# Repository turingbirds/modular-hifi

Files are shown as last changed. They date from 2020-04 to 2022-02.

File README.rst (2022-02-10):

Modular HiFi
============

A collection of Eurorack modules for home HiFi.

Typically, the PCB serves as a front panel while also carrying the circuit components on the back.

*Status: working prototypes. More documentation will follow!*

Modules
-------

Stereo mixer
~~~~~~~~~~~~

``stereo_3ch_mixer``

Three vertical slider potentiometers. Secondary (monitor) output. Quasi-differential inputs.

Phonograph preamplifier
~~~~~~~~~~~~~~~~~~~~~~~

``phono_preamp``

RIAA preamplifier and subsonic high-pass filter. 

Based on Rod Elliot <http://sound-au.com/> "Project 06" (RIAA pre-amp) and "Project 99" (subsonic filter)

Surround decoder
~~~~~~~~~~~~~~~~

``surround_decoder``

Stereo to 5.1 decoder. Separate volume controls for front, center, rear and subwoofer. Switchable subwoofer low-pass filter, adjustable between 50 and 500 Hz. Rear center channel "mix-in" control.

License
-------

`Open source hardware <https://www.oshwa.org/>`_ is hardware for which the design is made publicly available, so that anyone can study, modify, distribute, make, and sell the design or hardware based on that design, subject to the following license conditions.

Hardware licensed under the *CERN Open Hardware Licence Version 2 - Weakly Reciprocal,* a copy of which is included in this repository at `cern_ohl_w_v2.txt <https://github.com/turingbirds/modular-hifi/blob/master/cern_ohl_w_v2.txt>`_.

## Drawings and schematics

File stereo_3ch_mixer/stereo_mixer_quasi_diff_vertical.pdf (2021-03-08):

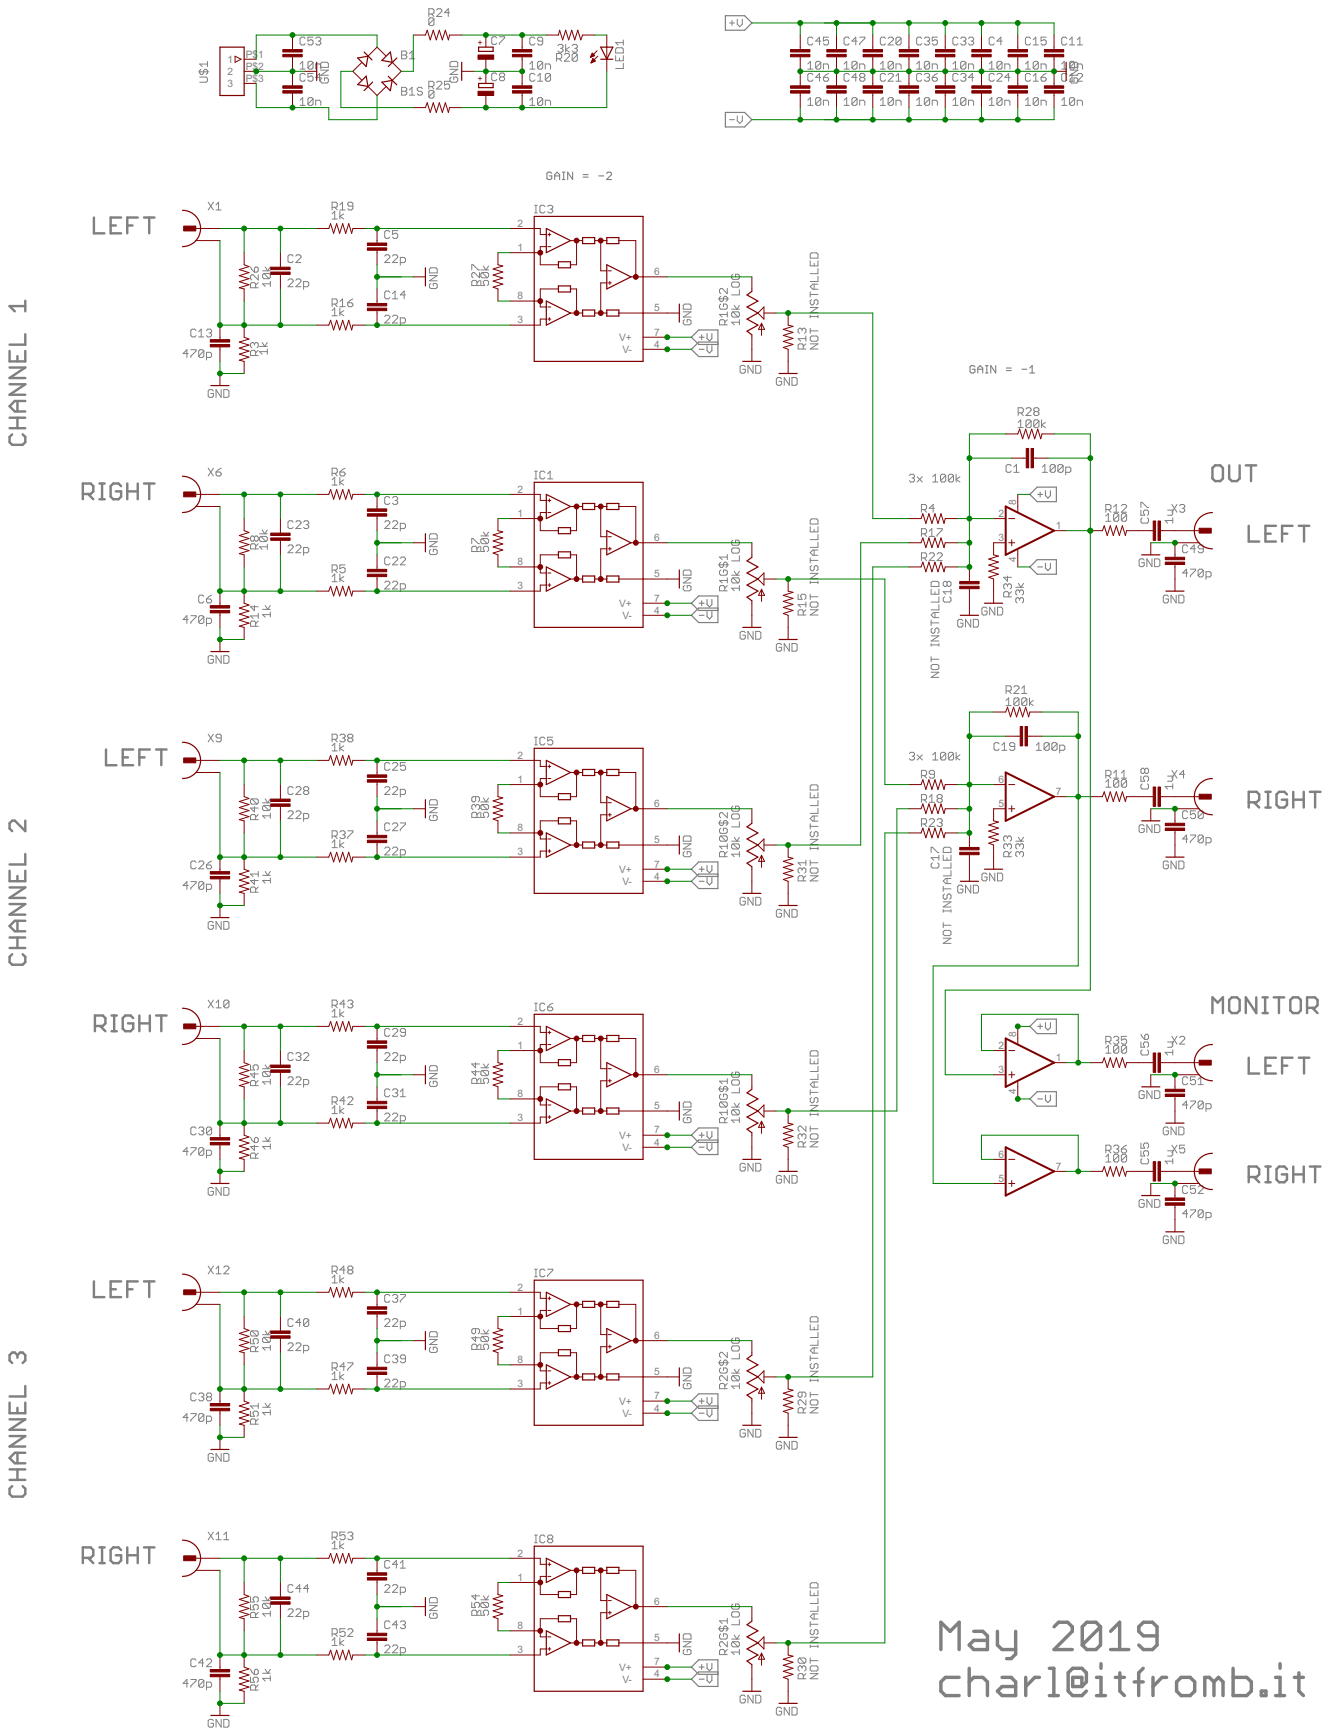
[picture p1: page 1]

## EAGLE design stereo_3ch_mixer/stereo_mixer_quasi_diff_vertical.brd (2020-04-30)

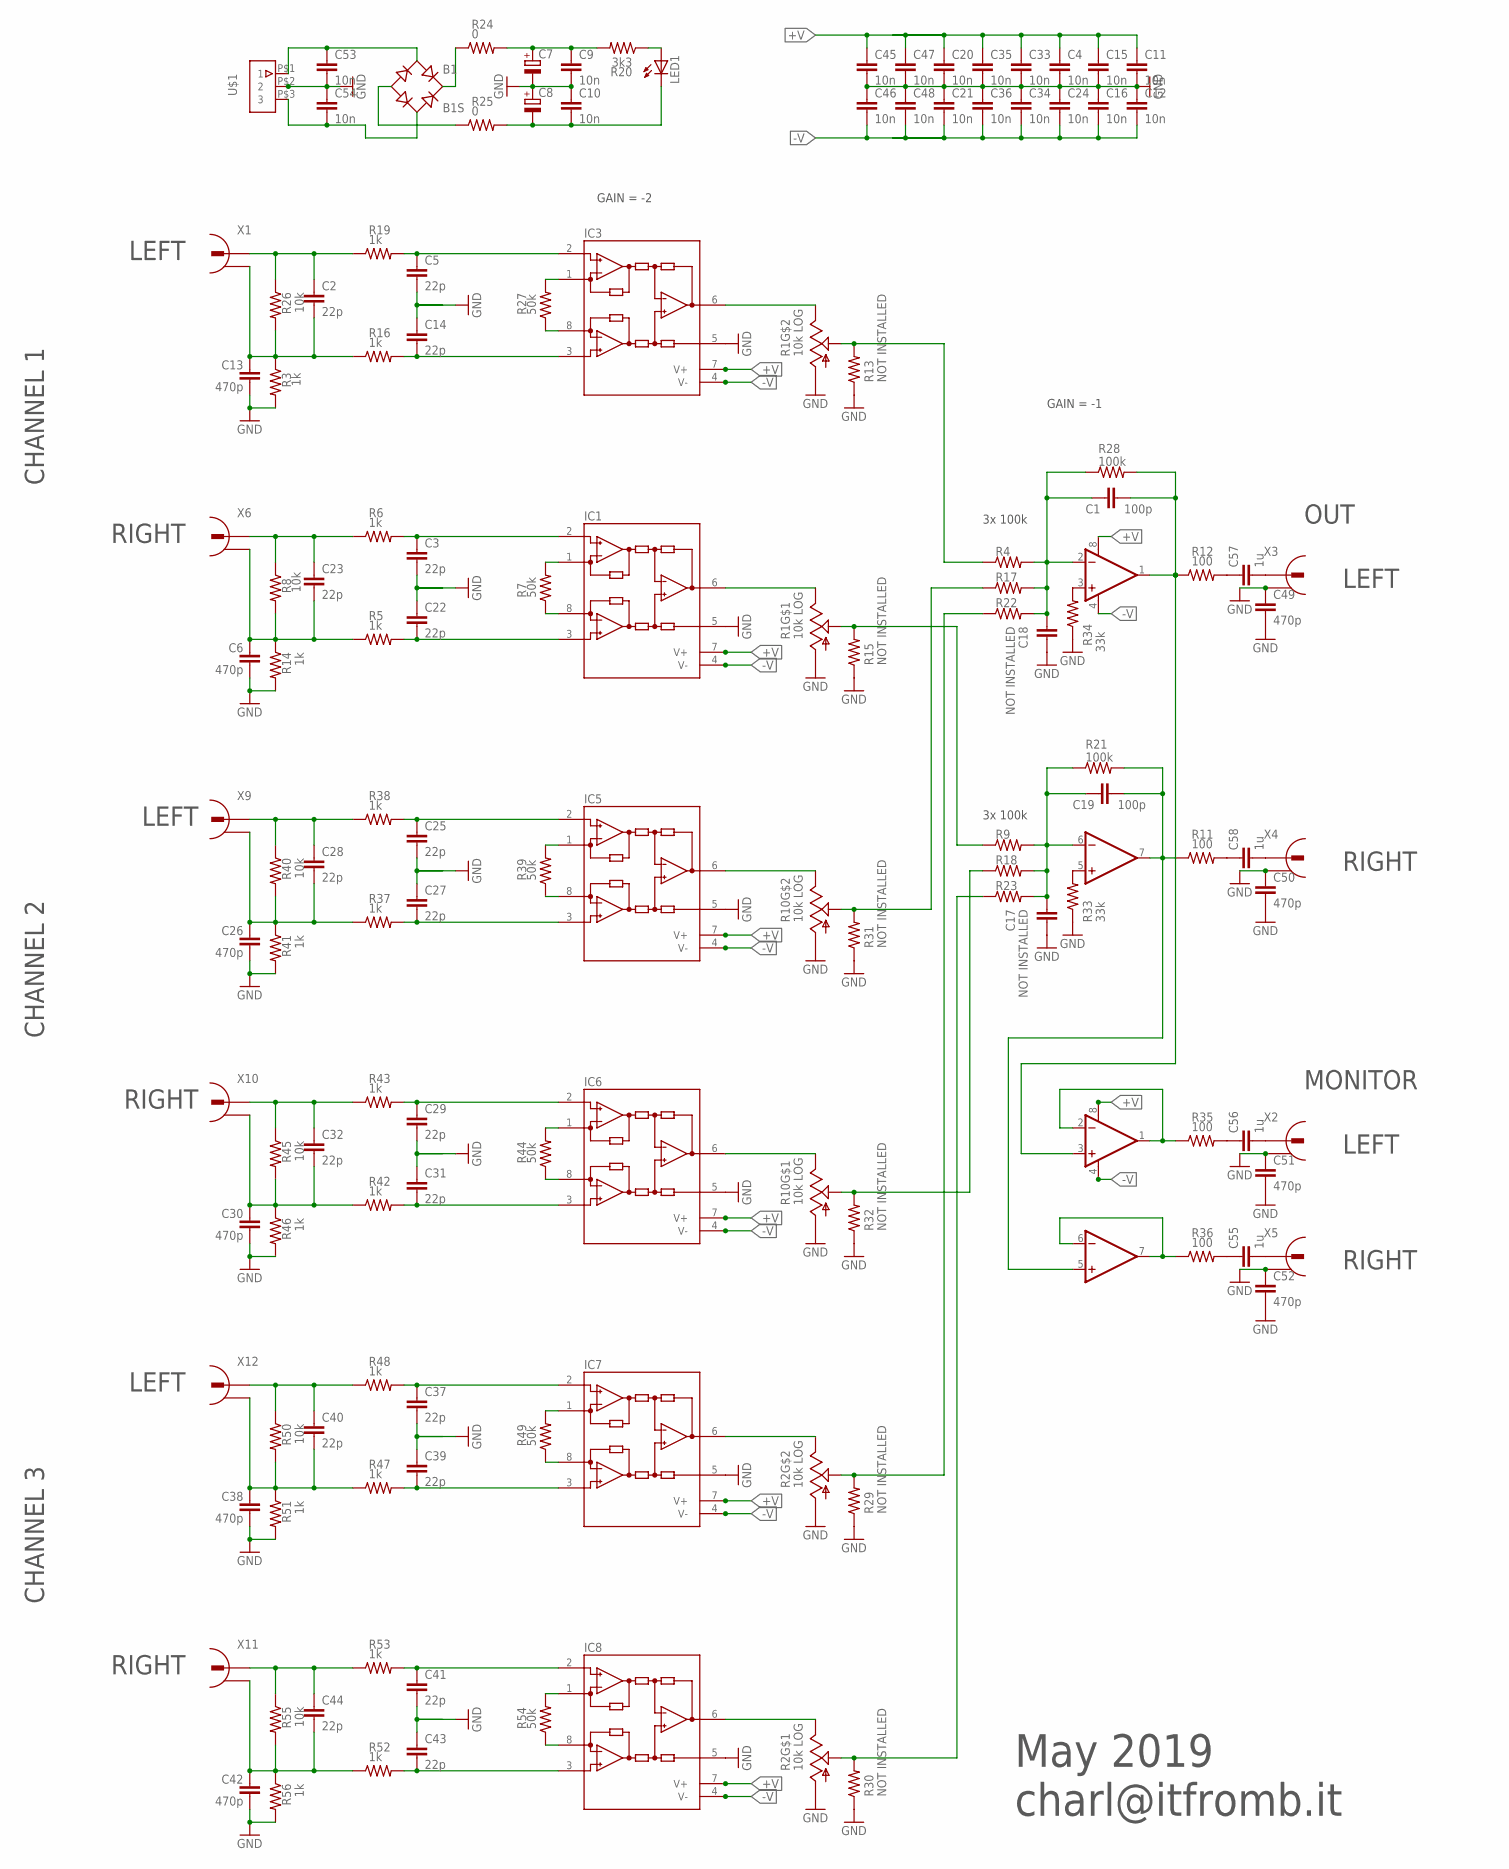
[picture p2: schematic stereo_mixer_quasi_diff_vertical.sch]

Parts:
B1: B1S; MBS
C1, C19: 100p; C1206
C2, C3, C5, C14, C22, C23, C25, C27, C28, C29, C31, C32, C37, C39, C40, C41, C43, C44: 22p; C1206
C4, C9, C10, C11, C12, C15, C16, C20, C21, C24, C33, C34, C35, C36, C45, C46, C47, C48, C53, C54: 10n; C1206
C6, C13, C26, C30, C38, C42, C49, C50, C51, C52: 470p; C1206
C7, C8: CPOL-EUSANYO_SMD_F12; SANYO-OSCON_SMD_F12
C17, C18: NOT INSTALLED; C1206
C55, C56, C57, C58: 1u; C1206
IC1, IC3, IC5, IC6, IC7, IC8: INA118U; SO08
IC2, IC4: OPAMP-DUALU; SO08
LED1: LEDCHIPLED_1206; CHIPLED_1206
R1, R2, R10: 10k LOG; SLIDE_POT_REAR_CONN
R3, R5, R6, R14, R16, R19, R37, R38, R41, R42, R43, R46, R47, R48, R51, R52, R53, R56: 1k; M1206
R4, R9, R17, R18, R21, R22, R23, R28: 100k; M1206
R7, R27, R39, R44, R49, R54: 50k; M1206
R8, R26, R40, R45, R50, R55: 10k; M1206
R11, R12, R35, R36: 100; M1206
R13, R15, R29, R30, R31, R32: NOT INSTALLED; M1206
R20: 3k3; M1206
R24, R25: 0; M1206
R33, R34: 33k; M1206
U$1: 3-PIN-JST-CONN-1.25MM-PITCH; S3B-PH-VERTICAL
X1, X6, X9, X10, X11, X12: 736880-49RCA-REAR-MOUNT; RCA-REAR-MOUNT
X2, X3, X4, X5: 736880-49; RCA-REAR-MOUNT-CENTER-ONLY

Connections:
+V: C4.1, C7.+, C9.1, C11.1, C15.1, C20.1, C33.1, C35.1, C45.1, C47.1, IC1.7 (V+), IC2.8 (V+), IC3.7 (V+), IC4.8 (V+), IC5.7 (V+), IC6.7 (V+), IC7.7 (V+), IC8.7 (V+), R20.2, R24.2
-V: C8.-, C10.2, C12.2, C16.2, C21.2, C24.2, C34.2, C36.2, C46.2, C48.2, IC1.4 (V-), IC2.4 (V-), IC3.4 (V-), IC4.4 (V-), IC5.4 (V-), IC6.4 (V-), IC7.4 (V-), IC8.4 (V-), LED1.C, R25.2
GND: C3.2, C4.2, C5.2, C6.2, C7.-, C8.+, C9.2, C10.1, C11.2, C12.1, C13.2, C14.1, C15.2, C16.1, C17.1, C18.1, C20.2, C21.1, C22.1, C24.1, C25.2, C26.2, C27.1, C29.2, C30.2, C31.1, C33.2, C34.1, C35.2, C36.1, C37.2, C38.2, C39.1, C41.2, C42.2, C43.1, C45.2, C46.1, C47.2, C48.1, C49.1, C49.2, C50.1, C50.2, C51.1, C51.2, C52.1, C52.2, C53.2, C54.1, IC1.5 (REF), IC3.5 (REF), IC5.5 (REF), IC6.5 (REF), IC7.5 (REF), IC8.5 (REF), R1.R1A (RA), R1.R2A (RA), R2.R1A (RA), R2.R2A (RA), R3.2, R10.R1A (RA), R10.R2A (RA), R13.1, R14.2, R15.1, R29.1, R30.1, R31.1, R32.1, R33.1, R34.1, R41.2, R46.2, R51.2, R56.2, U$1.P$2 (2), X2.SIGNAL (2), X3.SIGNAL (2), X4.SIGNAL (2), X5.SIGNAL (2)
unnamed: IC4.1 (OUT), IC4.2 (-IN), R35.1
unnamed: C2.1, R19.1, R26.1, X1.SIGNAL (1)
unnamed: C37.1, IC7.2 (-IN), R48.2
unnamed: IC3.6 (OUT), R1.R2B (RB)
unnamed: IC2.5 (+IN), R33.2
unnamed: R1.R2W (RW), R4.1, R13.2
unnamed: C38.1, C40.2, R47.1, R50.2, R51.1, X12.RING (2)
unnamed: R1.R1W (RW), R9.1, R15.2
unnamed: C19.2, IC2.7 (OUT), IC4.5 (+IN), R11.1, R21.2
unnamed: IC3.1 (RG), R27.2
unnamed: C3.1, IC1.2 (-IN), R6.2
unnamed: C25.1, IC5.2 (-IN), R38.2
unnamed: C6.1, C23.2, R5.1, R8.2, R14.1, X6.RING (2)
unnamed: C14.2, IC3.3 (+IN), R16.2
unnamed: C5.1, IC3.2 (-IN), R19.2
unnamed: C2.2, C13.1, R3.1, R16.1, R26.2, X1.RING (2)
unnamed: IC2.3 (+IN), R34.2
unnamed: C1.1, C18.2, IC2.2 (-IN), R4.2, R17.2, R22.2, R28.1
unnamed: C17.2, C19.1, IC2.6 (-IN), R9.2, R18.2, R21.1, R23.2
unnamed: C23.1, R6.1, R8.1, X6.SIGNAL (1)
unnamed: IC1.8 (RG), R7.1
unnamed: IC3.8 (RG), R27.1
unnamed: C22.2, IC1.3 (+IN), R5.2
unnamed: IC1.6 (OUT), R1.R1B (RB)
unnamed: R2.R2W (RW), R22.1, R29.2
unnamed: R2.R1W (RW), R23.1, R30.2
unnamed: IC1.1 (RG), R7.2
unnamed: B1.AC1, C53.1, U$1.P$1 (1)
unnamed: B1.+, R24.1
unnamed: B1.AC2, C54.2, U$1.P$3 (3)
unnamed: B1.-, R25.1
unnamed: IC4.6 (-IN), IC4.7 (OUT), R36.1
unnamed: LED1.A, R20.1
unnamed: C40.1, R48.1, R50.1, X12.SIGNAL (1)
unnamed: C1.2, IC2.1 (OUT), IC4.3 (+IN), R12.1, R28.2
unnamed: C26.1, C28.2, R37.1, R40.2, R41.1, X9.RING (2)
unnamed: C28.1, R38.1, R40.1, X9.SIGNAL (1)
unnamed: IC5.8 (RG), R39.1
unnamed: C27.2, IC5.3 (+IN), R37.2
unnamed: IC6.6 (OUT), R10.R1B (RB)
unnamed: IC5.1 (RG), R39.2
unnamed: C29.1, IC6.2 (-IN), R43.2
unnamed: C30.1, C32.2, R42.1, R45.2, R46.1, X10.RING (2)
unnamed: C32.1, R43.1, R45.1, X10.SIGNAL (1)
unnamed: IC6.8 (RG), R44.1
unnamed: C31.2, IC6.3 (+IN), R42.2
unnamed: IC5.6 (OUT), R10.R2B (RB)
unnamed: IC6.1 (RG), R44.2
unnamed: R10.R2W (RW), R17.1, R31.2
unnamed: R10.R1W (RW), R18.1, R32.2
unnamed: IC7.8 (RG), R49.1
unnamed: C39.2, IC7.3 (+IN), R47.2
unnamed: IC7.1 (RG), R49.2
unnamed: C41.1, IC8.2 (-IN), R53.2
unnamed: C42.1, C44.2, R52.1, R55.2, R56.1, X11.RING (2)
unnamed: C44.1, R53.1, R55.1, X11.SIGNAL (1)
unnamed: IC8.8 (RG), R54.1
unnamed: C43.2, IC8.3 (+IN), R52.2
unnamed: IC8.1 (RG), R54.2
unnamed: IC8.6 (OUT), R2.R1B (RB)
unnamed: IC7.6 (OUT), R2.R2B (RB)
unnamed: C55.1, R36.2
unnamed: C56.1, R35.2
unnamed: C57.1, R12.2
unnamed: C58.1, R11.2
unnamed: C57.2, X3.RING (1)
unnamed: C58.2, X4.RING (1)
unnamed: C56.2, X2.RING (1)
unnamed: C55.2, X5.RING (1)

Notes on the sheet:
CHANNEL 1
LEFT
RIGHT
OUT
CHANNEL 2
CHANNEL 3
MONITOR
GAIN = -2
GAIN = -1
3x 100k
May 2019 charl@itfromb.it

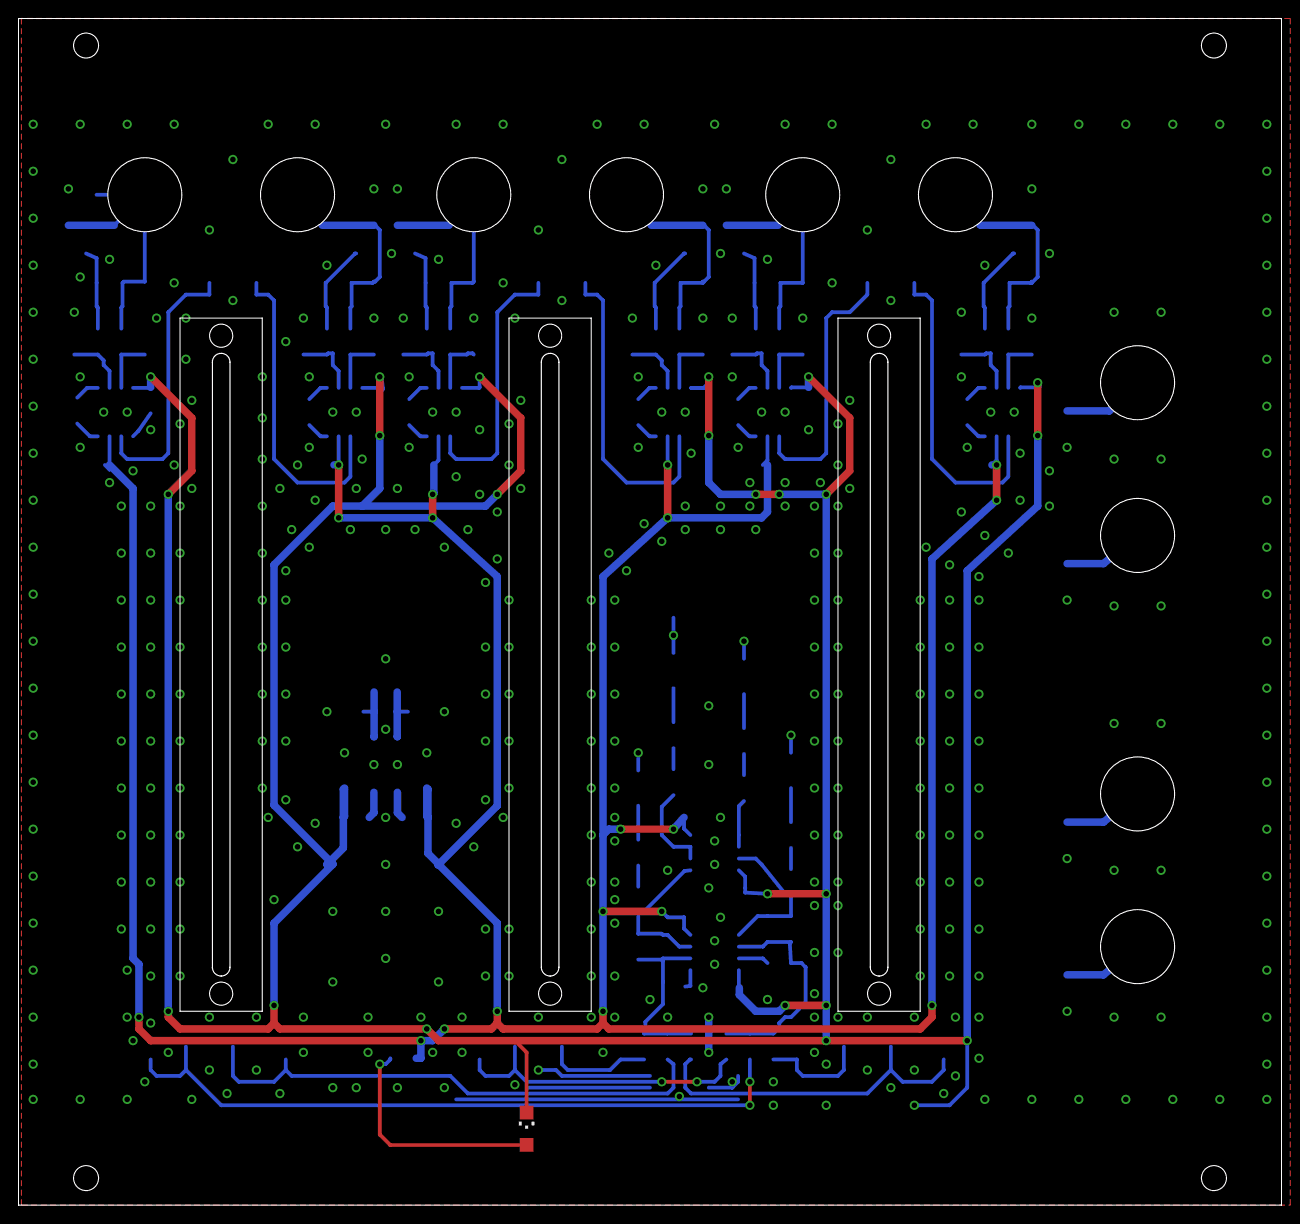
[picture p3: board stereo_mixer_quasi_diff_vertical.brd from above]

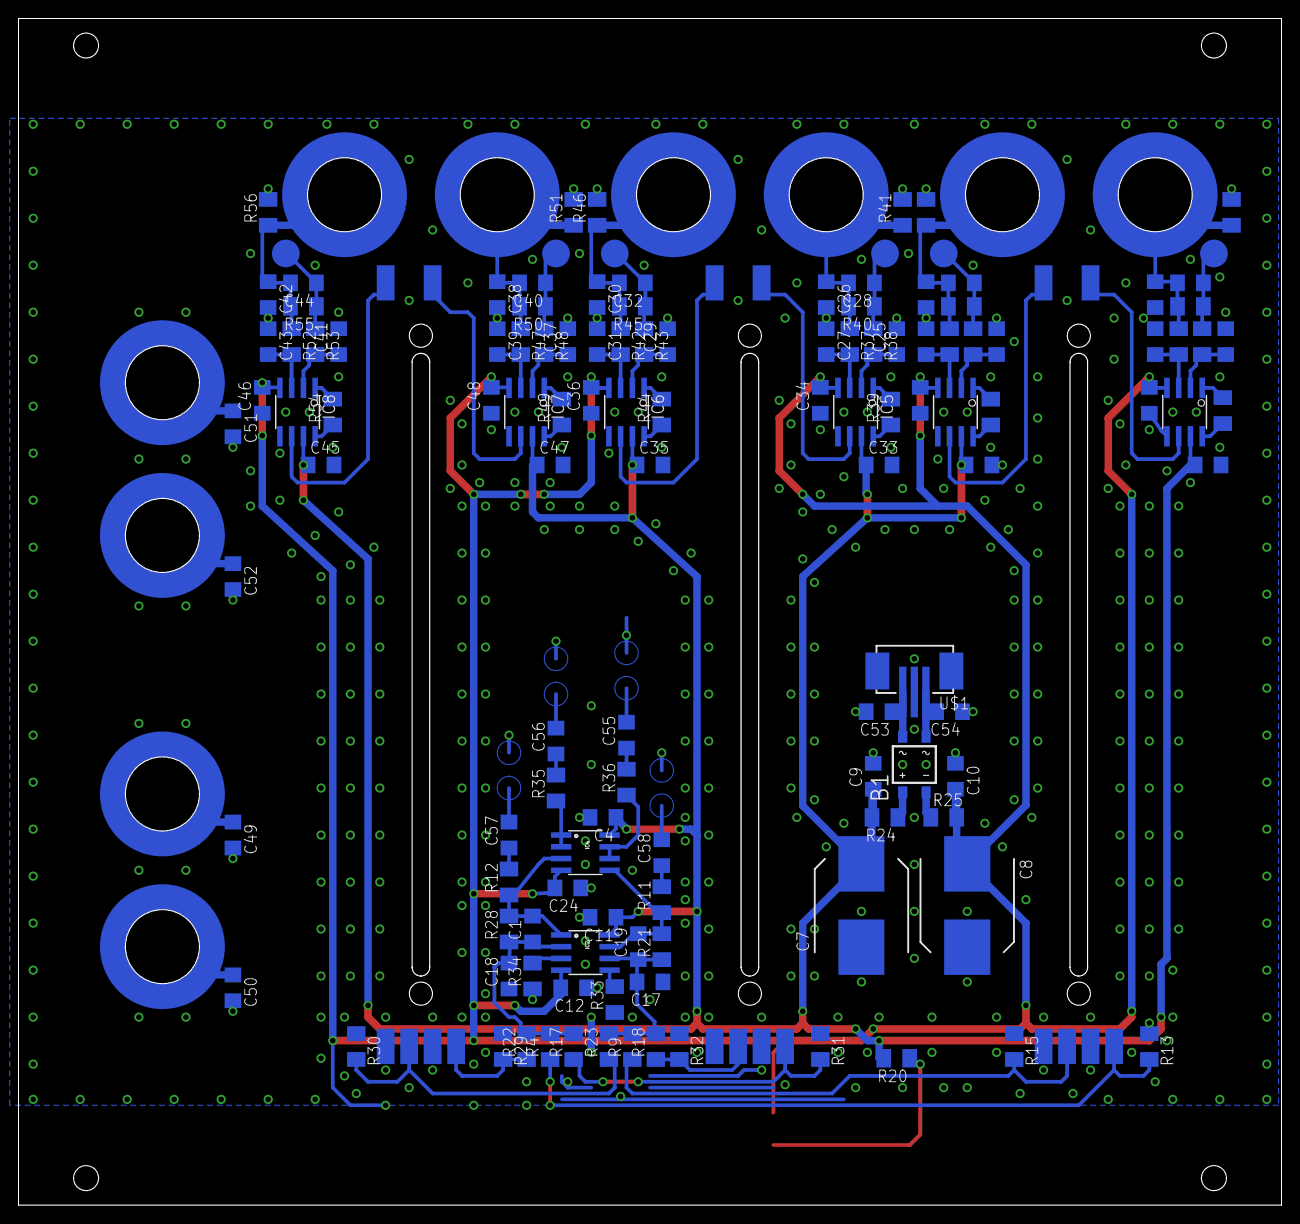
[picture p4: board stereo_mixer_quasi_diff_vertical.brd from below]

Board: 2 copper layers, 136.5 x 128.3 mm, 135 parts (121 on the bottom side), 72 nets.

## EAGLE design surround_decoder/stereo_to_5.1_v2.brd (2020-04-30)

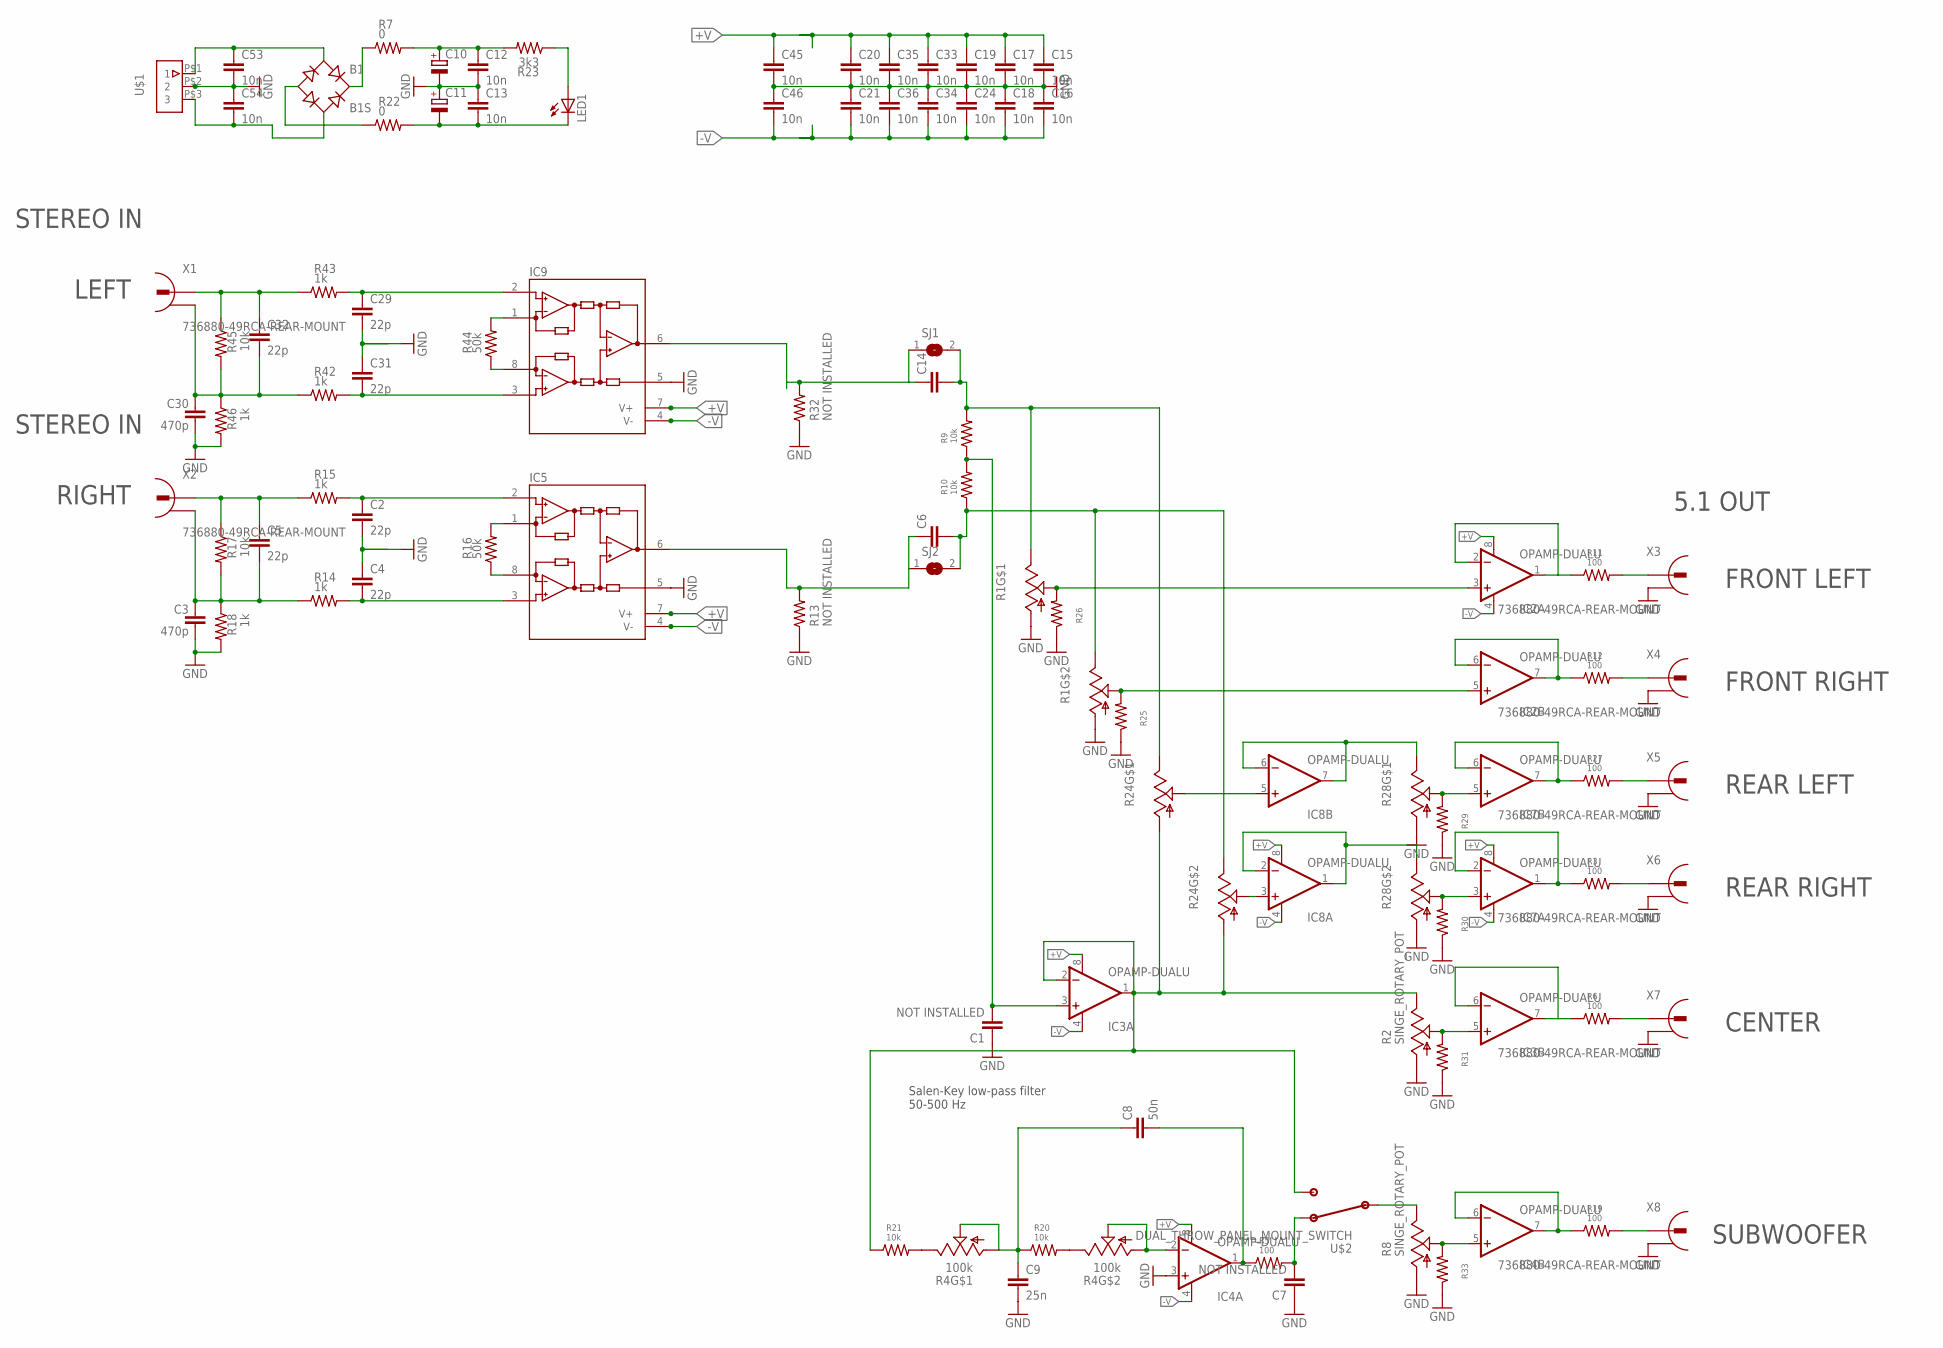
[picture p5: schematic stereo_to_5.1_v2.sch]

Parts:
B1: B1S; MBS
C1, C7: NOT INSTALLED; C1206
C2, C4, C5, C29, C31, C32: 22p; C1206
C3, C30: 470p; C1206
C6, C14: C-EUC4532; C4532
C8: 50n; C1206
C9: 25n; C1206
C10, C11: CPOL-EUSANYO_SMD_F12; SANYO-OSCON_SMD_F12
C12, C13, C15, C16, C17, C18, C19, C20, C21, C24, C33, C34, C35, C36, C45, C46, C53, C54: 10n; C1206
IC2, IC3, IC4, IC7, IC8: OPAMP-DUALU; SO08
IC5, IC9: ad620; SO08
LED1: LEDCHIPLED_1206; CHIPLED_1206
R1, R24, R28: TRIM_US-ROTARY; DUAL_GANGED_ROTARY_POT
R2, R8: SINGE_ROTARY_POT; SINGLE_ROTARY_POT
R3, R5, R6, R11, R12, R19, R27: 100; M1206
R4: 100k; DUAL_GANGED_ROTARY_POT
R7, R22: 0; M1206
R9, R10, R17, R20, R21, R45: 10k; M1206
R13, R32: NOT INSTALLED; M1206
R14, R15, R18, R42, R43, R46: 1k; M1206
R16, R44: 50k; M1206
R23: 3k3; M1206
R25, R26, R29, R30, R31, R33: R-US_M1206; M1206
SJ1, SJ2: SJ
U$1: 3-PIN-JST-CONN-1.25MM-PITCH; S3B-PH-VERTICAL
U$2: DUAL_THROW_PANEL_MOUNT_SWITCH; PANEL_MOUNT_DUAL_THROW_SWITCH
X1, X2, X3, X4, X5, X6, X7, X8: 736880-49RCA-REAR-MOUNT; RCA-REAR-MOUNT

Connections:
+V: C10.+, C12.1, C15.1, C17.1, C19.1, C20.1, C33.1, C35.1, C45.1, IC2.8 (V+), IC3.8 (V+), IC4.8 (V+), IC5.7 (V+), IC7.8 (V+), IC8.8 (V+), IC9.7 (V+), R7.2, R23.2
-V: C11.-, C13.2, C16.2, C18.2, C21.2, C24.2, C34.2, C36.2, C46.2, IC2.4 (V-), IC3.4 (V-), IC4.4 (V-), IC5.4 (V-), IC7.4 (V-), IC8.4 (V-), IC9.4 (V-), LED1.C, R22.2
GND: C1.1, C2.2, C3.2, C4.1, C7.1, C9.2, C10.-, C11.+, C12.2, C13.1, C15.2, C16.1, C17.2, C18.1, C19.2, C20.2, C21.1, C24.1, C29.2, C30.2, C31.1, C33.2, C34.1, C35.2, C36.1, C45.2, C46.1, C53.2, C54.1, IC4.3 (+IN), IC5.5 (REF), IC9.5 (REF), R1.P$2 (RA), R1.P$5 (RA), R2.P$2 (RA), R8.P$2 (RA), R13.1, R18.2, R25.1, R26.1, R28.P$2 (RA), R28.P$5 (RA), R29.1, R30.1, R31.1, R32.1, R33.1, R46.2, U$1.P$2 (2), X3.RING (2), X4.RING (2), X5.RING (2), X6.RING (2), X7.RING (2), X8.RING (2)
unnamed: C14.2, R1.P$3 (RB), R9.2, R24.P$3 (RB), SJ1.2
unnamed: C7.2, R5.2, U$2.LEFT (NC)
unnamed: R8.P$3 (RB), U$2.MIDDLE (COMMON)
unnamed: IC4.5 (+IN), R8.P$1 (RW), R33.2
unnamed: IC4.6 (-IN), IC4.7 (OUT), R19.1
unnamed: C6.2, R1.P$6 (RB), R10.1, R24.P$6 (RB), SJ2.2
unnamed: IC7.5 (+IN), R28.P$1 (RW), R29.2
unnamed: IC2.1 (OUT), IC2.2 (-IN), R11.1
unnamed: IC2.3 (+IN), R1.P$1 (RW), R26.2
unnamed: IC2.5 (+IN), R1.P$4 (RW), R25.2
unnamed: IC2.6 (-IN), IC2.7 (OUT), R12.1
unnamed: IC3.5 (+IN), R2.P$1 (RW), R31.2
unnamed: R11.2, X3.SIGNAL (1)
unnamed: R12.2, X4.SIGNAL (1)
unnamed: C8.2, IC4.1 (OUT), R5.1
unnamed: IC7.3 (+IN), R28.P$4 (RW), R30.2
unnamed: C2.1, IC5.2 (-IN), R15.2
unnamed: C3.1, C5.2, R14.1, R17.2, R18.1, X2.RING (2)
unnamed: C5.1, R15.1, R17.1, X2.SIGNAL (1)
unnamed: IC5.8 (RG), R16.1
unnamed: C4.2, IC5.3 (+IN), R14.2
unnamed: IC5.1 (RG), R16.2
unnamed: C6.1, IC5.6 (OUT), R13.2, SJ2.1
unnamed: IC7.1 (OUT), IC7.2 (-IN), R3.1
unnamed: R3.2, X6.SIGNAL (1)
unnamed: R4.P$6 (RB), R20.2
unnamed: R4.P$3 (RB), R21.2
unnamed: C1.2, IC3.3 (+IN), R9.1, R10.2
unnamed: IC3.1 (OUT), IC3.2 (-IN), R2.P$3 (RB), R21.1, R24.P$2 (RA), R24.P$5 (RA), U$2.RIGHT (NO)
unnamed: IC7.6 (-IN), IC7.7 (OUT), R27.1
unnamed: IC3.6 (-IN), IC3.7 (OUT), R6.1
unnamed: R27.2, X5.SIGNAL (1)
unnamed: R6.2, X7.SIGNAL (1)
unnamed: IC8.5 (+IN), R24.P$1 (RW)
unnamed: IC8.3 (+IN), R24.P$4 (RW)
unnamed: IC8.1 (OUT), IC8.2 (-IN), R28.P$6 (RB)
unnamed: IC8.6 (-IN), IC8.7 (OUT), R28.P$3 (RB)
unnamed: R19.2, X8.SIGNAL (1)
unnamed: IC4.2 (-IN), R4.P$4 (RW), R4.P$5 (RA)
unnamed: C8.1, C9.1, R4.P$1 (RW), R4.P$2 (RA), R20.1
unnamed: B1.AC1, C53.1, U$1.P$1 (1)
unnamed: B1.+, R7.1
unnamed: C14.1, IC9.6 (OUT), R32.2, SJ1.1
unnamed: B1.AC2, C54.2, U$1.P$3 (3)
unnamed: C29.1, IC9.2 (-IN), R43.2
unnamed: C30.1, C32.2, R42.1, R45.2, R46.1, X1.RING (2)
unnamed: C32.1, R43.1, R45.1, X1.SIGNAL (1)
unnamed: IC9.8 (RG), R44.1
unnamed: C31.2, IC9.3 (+IN), R42.2
unnamed: B1.-, R22.1
unnamed: IC9.1 (RG), R44.2
unnamed: LED1.A, R23.1

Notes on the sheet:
STEREO IN
FRONT LEFT
FRONT RIGHT
REAR LEFT
REAR RIGHT
CENTER
SUBWOOFER
LEFT
RIGHT
5.1 OUT
Salen-Key low-pass filter 50-500 Hz

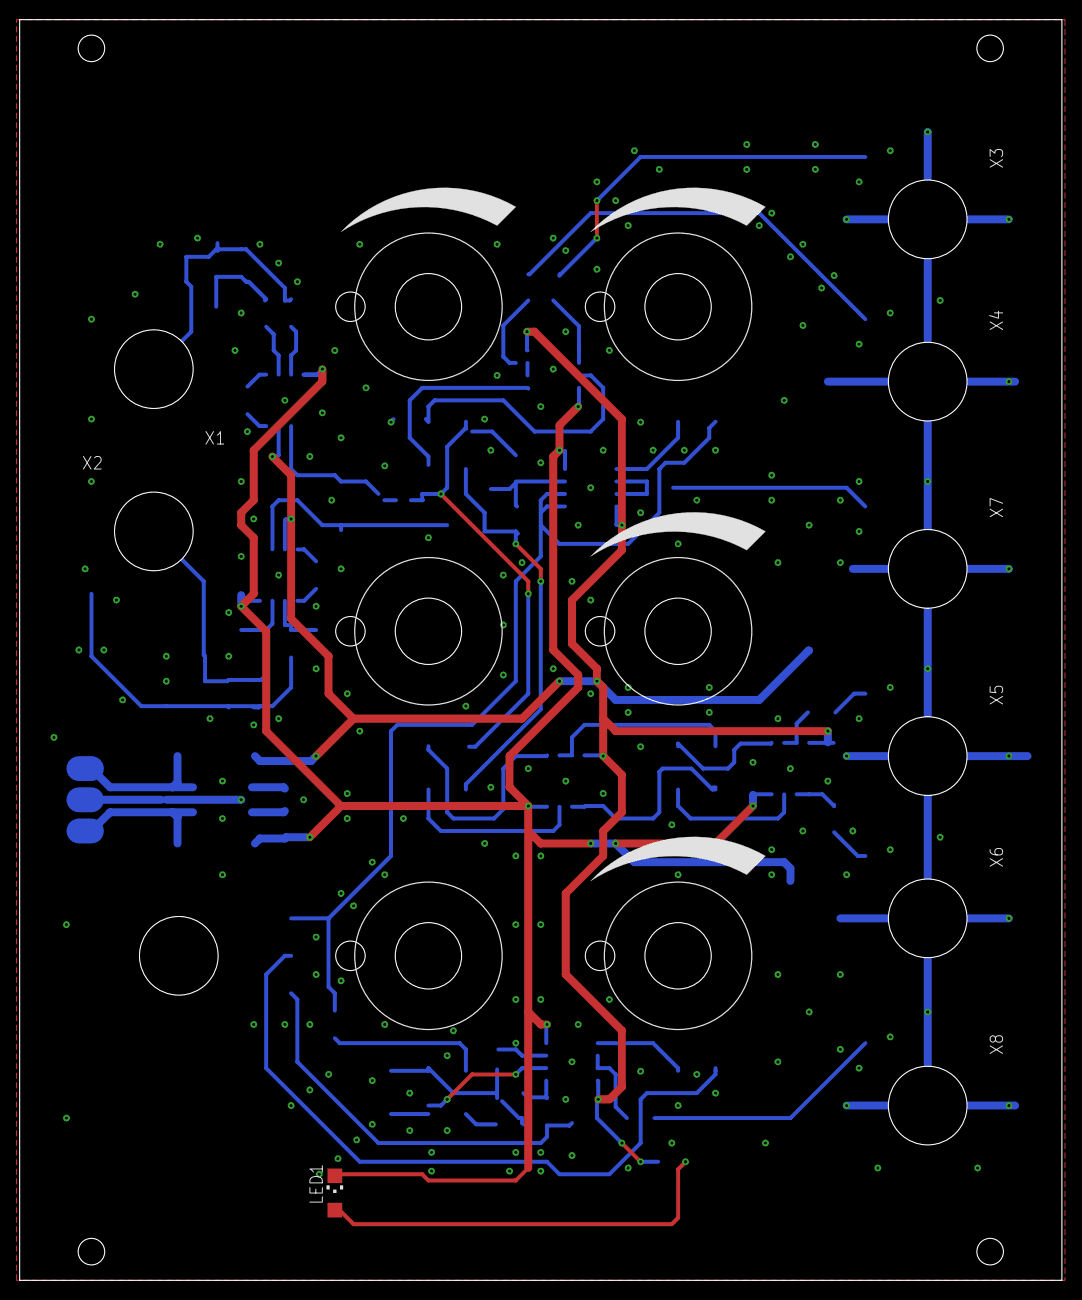
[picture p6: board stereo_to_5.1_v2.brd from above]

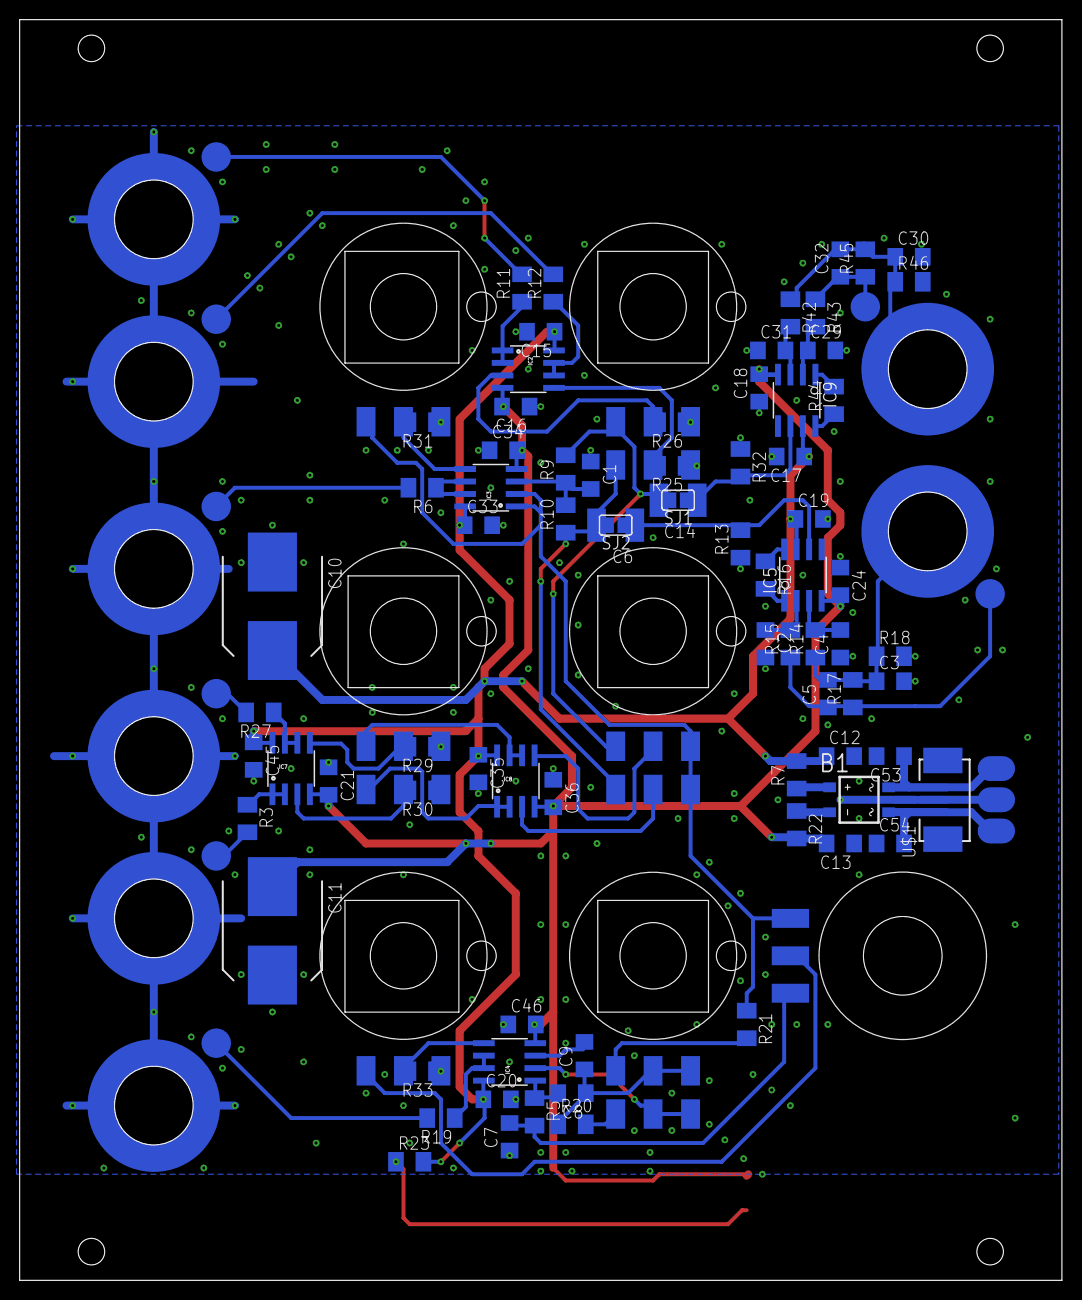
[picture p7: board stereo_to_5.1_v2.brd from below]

Board: 2 copper layers, 106.0 x 128.3 mm, 93 parts (77 on the bottom side), 55 nets.

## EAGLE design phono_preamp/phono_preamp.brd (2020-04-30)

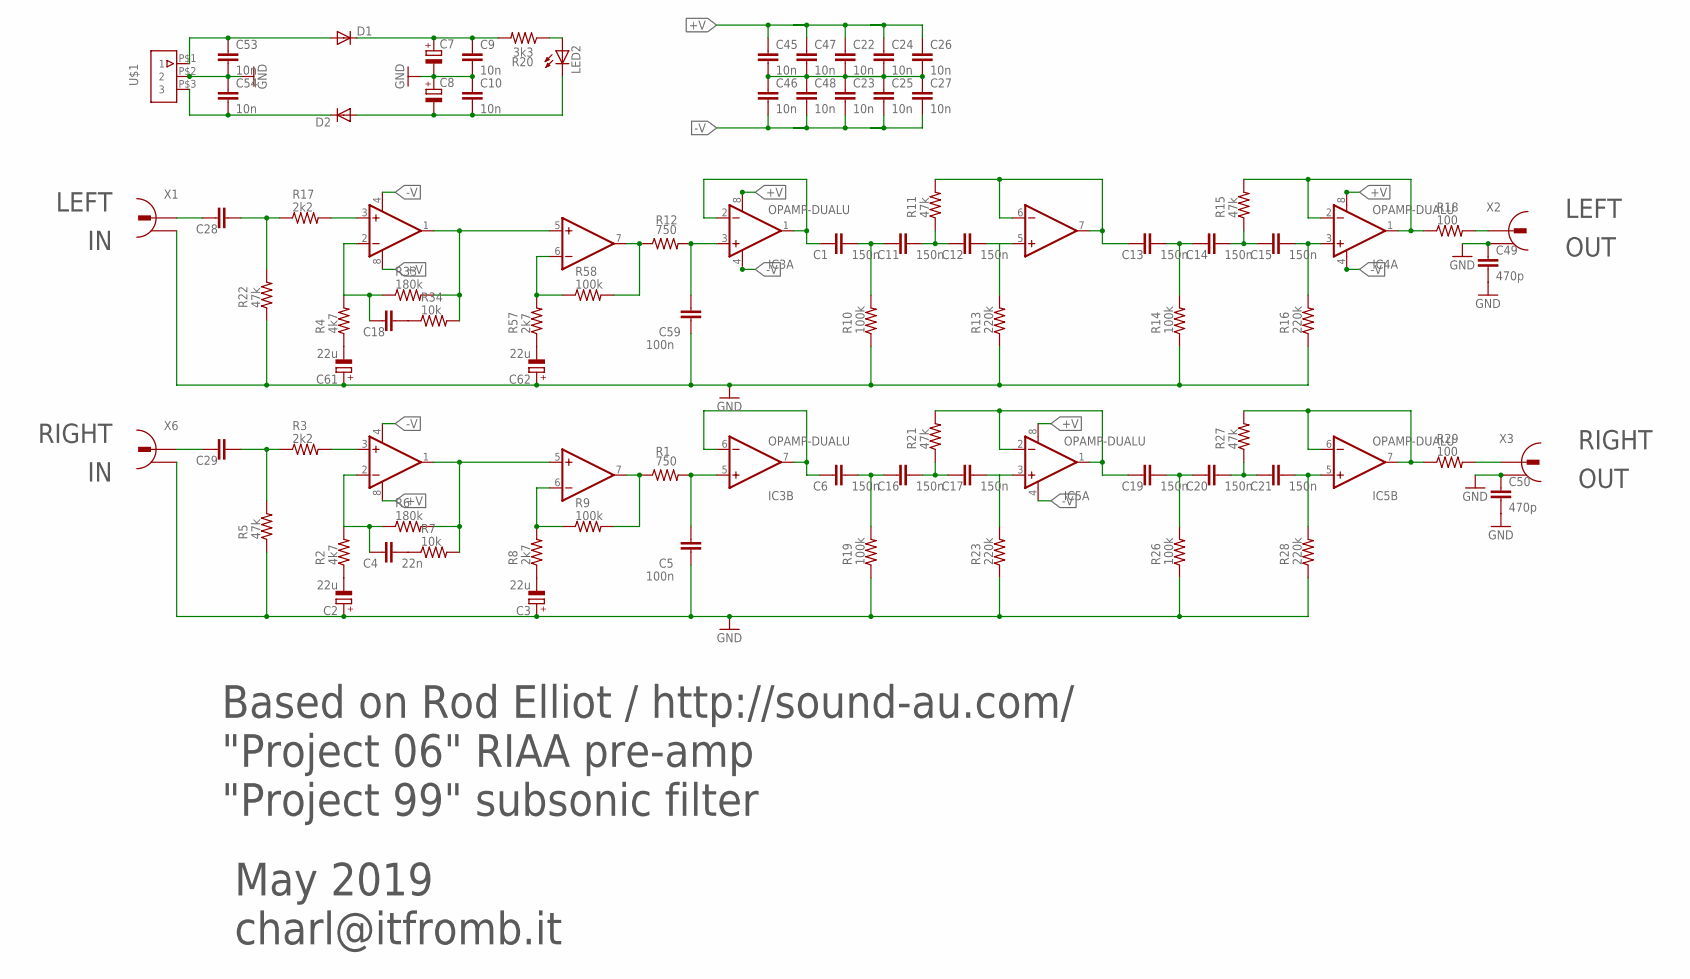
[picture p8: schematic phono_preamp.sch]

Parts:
C1, C6, C11, C12, C13, C14, C15, C16, C17, C19, C20, C21: 150n; C1206
C2, C3, C61, C62: 22u; PANASONIC_C
C4, C18: 22n; C1206
C5, C59: 100n; C1206
C7, C8: CPOL-EUSANYO_SMD_F12; SANYO-OSCON_SMD_F12
C9, C10, C22, C23, C24, C25, C26, C27, C45, C46, C47, C48, C53, C54: 10n; C1206
C28, C29: C-EUC1206; C1206
C49, C50: 470p; C1206
D1, D2: DIODE-DO214AA; DO214AA
IC1, IC2, IC3, IC4, IC5: OPAMP-DUALU; SO08
LED2: LEDCHIPLED_1206; CHIPLED_1206
R1, R12: 750; M1206
R2, R4: 4k7; M1206
R3, R17: 2k2; M1206
R5, R11, R15, R21, R22, R27: 47k; M1206
R6, R33: 180k; M1206
R7, R34: 10k; M1206
R8, R57: 2k7; M1206
R9, R10, R14, R19, R26, R58: 100k; M1206
R13, R16, R23, R28: 220k; M1206
R18, R29: 100; M1206
R20: 3k3; M1206
U$1: 3-PIN-JST-CONN-1.25MM-PITCH; S3B-PH-VERTICAL
X1, X2, X3, X6: 736880-49RCA-REAR-MOUNT; RCA-REAR-MOUNT

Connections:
+V: C7.+, C9.1, C22.1, C24.1, C26.1, C45.1, C47.1, D1.C, IC1.8 (V+), IC2.8 (V+), IC3.8 (V+), IC4.8 (V+), IC5.8 (V+), R20.2
-V: C8.-, C10.2, C23.2, C25.2, C27.2, C46.2, C48.2, D2.A, IC1.4 (V-), IC2.4 (V-), IC3.4 (V-), IC4.4 (V-), IC5.4 (V-), LED2.C
GND: C2.+, C3.+, C5.1, C7.-, C8.+, C9.2, C10.1, C22.2, C23.1, C24.2, C25.1, C26.2, C27.1, C45.2, C46.1, C47.2, C48.1, C49.1, C49.2, C50.1, C50.2, C53.2, C54.1, C59.1, C61.+, C62.+, R5.1, R10.1, R13.1, R14.1, R16.1, R19.1, R22.1, R23.1, R26.1, R28.1, U$1.P$2 (2), X1.RING (2), X2.RING (2), X3.RING (2), X6.RING (2)
unnamed: C1.1, IC3.1 (OUT), IC3.2 (-IN)
unnamed: C5.2, IC3.5 (+IN), R1.2
unnamed: C13.1, IC4.6 (-IN), IC4.7 (OUT), R11.2
unnamed: C2.-, R2.1
unnamed: C4.1, IC1.2 (-IN), R2.2, R6.1
unnamed: C61.-, R4.1
unnamed: C29.2, R3.1, R5.2
unnamed: IC1.3 (+IN), R3.2
unnamed: C4.2, R7.1
unnamed: IC1.1 (OUT), IC1.5 (+IN), R6.2, R7.2
unnamed: C3.-, R8.1
unnamed: IC1.6 (-IN), R8.2, R9.1
unnamed: IC1.7 (OUT), R1.1, R9.2
unnamed: C12.2, IC4.5 (+IN), R13.2
unnamed: C11.2, C12.1, R11.1
unnamed: C1.2, C11.1, R10.2
unnamed: R18.2, X2.SIGNAL (1)
unnamed: IC4.1 (OUT), IC4.2 (-IN), R15.2, R18.1
unnamed: C15.2, IC4.3 (+IN), R16.2
unnamed: C18.1, IC2.2 (-IN), R4.2, R33.1
unnamed: C14.2, C15.1, R15.1
unnamed: C28.2, R17.1, R22.2
unnamed: C13.2, C14.1, R14.2
unnamed: C6.1, IC3.6 (-IN), IC3.7 (OUT)
unnamed: C19.1, IC5.1 (OUT), IC5.2 (-IN), R21.2
unnamed: C17.2, IC5.3 (+IN), R23.2
unnamed: C16.2, C17.1, R21.1
unnamed: C6.2, C16.1, R19.2
unnamed: IC5.6 (-IN), IC5.7 (OUT), R27.2, R29.1
unnamed: C21.2, IC5.5 (+IN), R28.2
unnamed: C20.2, C21.1, R27.1
unnamed: C53.1, D1.A, U$1.P$1 (1)
unnamed: C54.2, D2.C, U$1.P$3 (3)
unnamed: C19.2, C20.1, R26.2
unnamed: LED2.A, R20.1
unnamed: R29.2, X3.SIGNAL (1)
unnamed: IC2.3 (+IN), R17.2
unnamed: C28.1, X1.SIGNAL (1)
unnamed: C29.1, X6.SIGNAL (1)
unnamed: IC2.7 (OUT), R12.1, R58.2
unnamed: C18.2, R34.1
unnamed: C59.2, IC3.3 (+IN), R12.2
unnamed: IC2.1 (OUT), IC2.5 (+IN), R33.2, R34.2
unnamed: C62.-, R57.1
unnamed: IC2.6 (-IN), R57.2, R58.1

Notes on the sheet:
LEFT
RIGHT
OUT
May 2019 charl@itfromb.it
Based on Rod Elliot / http://sound-au.com/ "Project 06" RIAA pre-amp "Project 99" subsonic filter

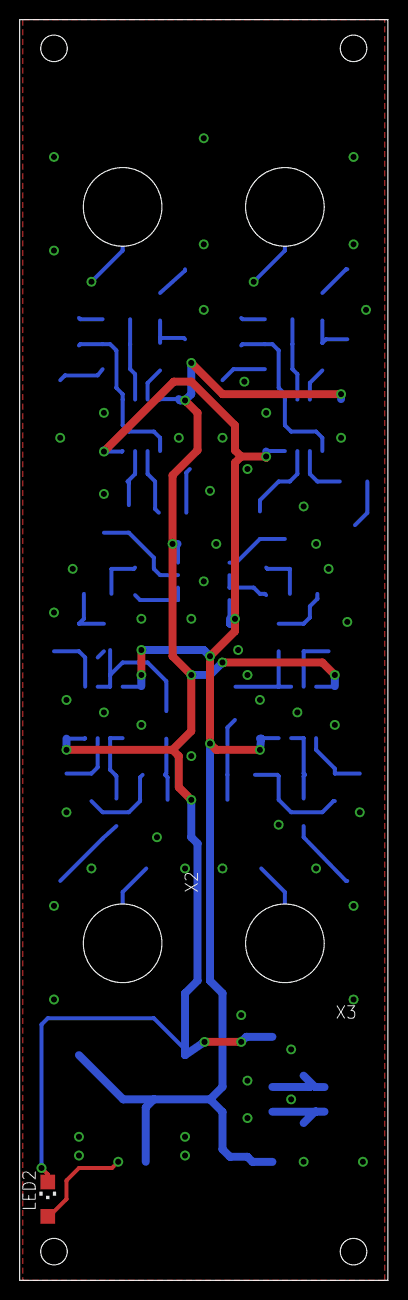
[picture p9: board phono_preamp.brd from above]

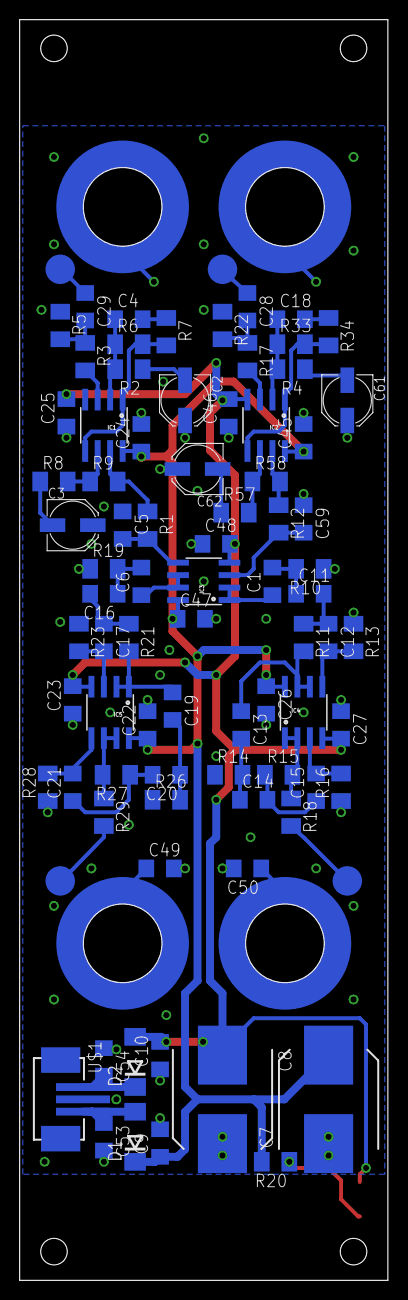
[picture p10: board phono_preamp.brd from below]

Board: 2 copper layers, 37.5 x 128.3 mm, 84 parts (79 on the bottom side), 48 nets.
